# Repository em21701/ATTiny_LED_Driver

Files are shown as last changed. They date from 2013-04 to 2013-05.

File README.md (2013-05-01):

ATTiny_LED_Driver
=================

LED Driver Board using and ATTiny processor for PWM and effects.

The goal of this project is to use the ATTiny as a Buck Driver for High Brightness LEDs. 
After getting a functional Buck Driver working I will add blink effects.

This driver board has 2 inputs and is intended for use as a turn signal/running light 
combo and brake light/running light combo for a motorcycle. As such the board has 2 inputs,
one for 12v power from the key and a second for 12v power from either the turn signal or 
brake light. The Key inuput will illuminate the LEDs to a low level and the second input 
will change the brightness to a significantly higher level.Blink effects will be added when 
used as a tail/brake combo to make the light more conspicuous. 

Currently planned blink effects are an invverted heartbeat and flash and fade. In the heart 
beat pattern the light will dim in a lub-dub pattern while brake light is illuminated. 
In the flash and fade pattern, the brake light will flash to full brightness then slowly fade
to a level brighter than running light level, but noticeably lower than full brightness. The
light will then flash back to full brightness and repeat.

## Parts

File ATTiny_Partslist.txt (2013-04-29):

Partlist

Exported from ATTiny5.sch at 4/17/13 7:26 PM

EAGLE Version 6.4.0 Copyright (c) 1988-2013 CadSoft

Assembly variant: 

Part     Value           Device          Package          Library                    Sheet

C1       .1u             C-USC0805       C0805            resistor                   1
C2       .1u             C-USC0805       C0805            resistor                   1
D1       CD1206-B260     CD1206-B260     D1206            Personal                   1
L1       B82442H1104K    B82442H1104K    B82442H          Personal                   1
Q1       BSP100          BSP100          SOT223           Personal                   1
R1       10k             R-US_R1206      R1206            resistor                   1
R2       .1              R-US_R1206      R1206            resistor                   1
R3       10k             R-US_R1206      R1206            resistor                   1
R4       900             R-US_R1206      R1206            resistor                   1
R5       300             R-US_R1206      R1206            resistor                   1
U1       SPX5205M5-L-3-3 SPX5205M5-L-3-3 SOT95P280X145-5N Exar_By_element14_Batch_1  1
U2       ATTINY5-TSHR    ATTINY5-TSHR    SOT95P280X145-6N Atmel_By_element14_Batch_1 1
X1       DIODES          MPT2            2POL254          con-phoenix-254            1
X2                       MPT3            3POL254          con-phoenix-254            1

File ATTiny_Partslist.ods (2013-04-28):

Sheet: Parts List
Part | Value | Package | Qty | $ | Sub $ | Digikey
C1,C2 | .1u | C0805 | 2 | 0.1 | 0.2 | 445-7534-1-ND
D1 | CD1206-B260 | D1206 | 1 | 0.47 | 0.47 | CD1206-B260CT-ND
L1 | 100u |  | 1 | 0.54 | 0.54 | SRN8040-101MCT-ND
Q1 | BSP100 | SOT223 | 1 | 0.69 | 0.69 | 568-6956-1-ND
R1,R3 | 10k | R1206 | 2 | 0.094 | 0.188 | 541-10KECT-ND
R2 | 1 | R1206 | 1 | 0.1 | 0.1 | CRM1206-JW-1R0ELFCT-ND
R4 | 900 | R1206 | 1 | 0.1 | 0.1 | P910ECT-ND
R5 | 300 | R1206 | 1 | 0.1 | 0.1 | P300ECT-ND
U1 | SPX5205M5-L-3-3 | SOT95P280X145-5N | 1 | 0.66 | 0.66 | 1016-1878-1-ND
U2 | ATTINY5-TSHR | SOT95P280X145-6N | 1 | 0.67 | 0.67 | ATTINY5-TSHRCT-ND
 |  |  |  | Total | 3.718

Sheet: Pinouts
Mounting Holes
x | y | size
0.060 | 0.530 | 0.125
1.120 | 0.060 | 0.125
Programming pins
x | y | Connection
0.200 | 0.375 | GND
0.390 | 0.280 | TPICLK
0.350 | 0.210 | V+
0.570 | 0.400 | TPIDATA
0.590 | 0.275 | RESET

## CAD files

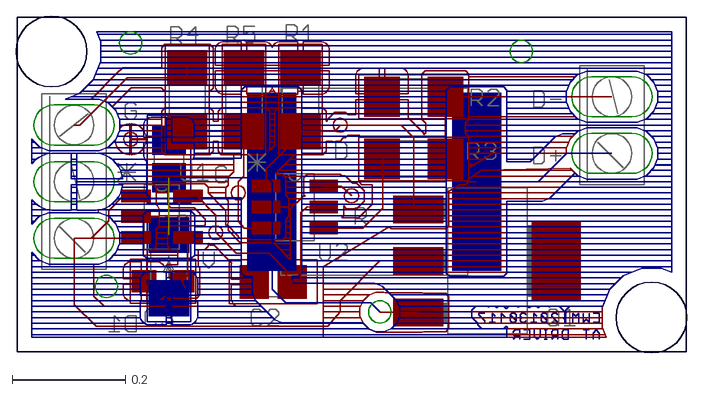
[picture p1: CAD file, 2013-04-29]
ATTiny5.dxf
1.19 x 0.595

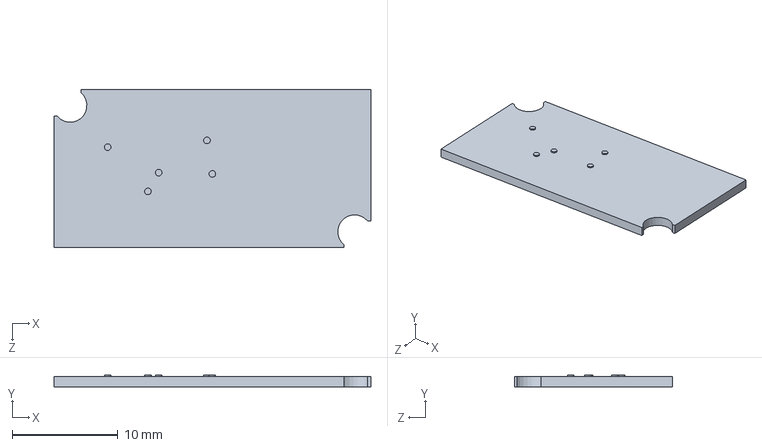
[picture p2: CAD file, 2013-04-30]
Programmer/Board.SLDPRT
30.0 x 1.13 x 15.0 mm

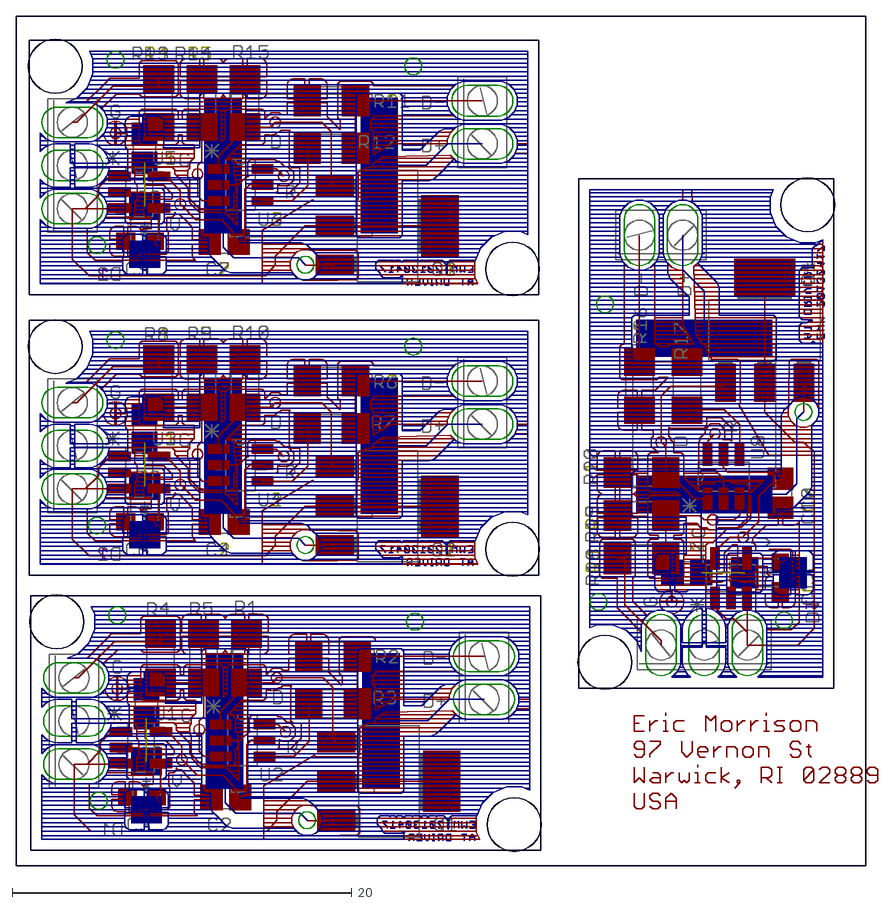
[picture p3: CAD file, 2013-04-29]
Panel/ATTinyPanel.dxf
50.7 x 50.0

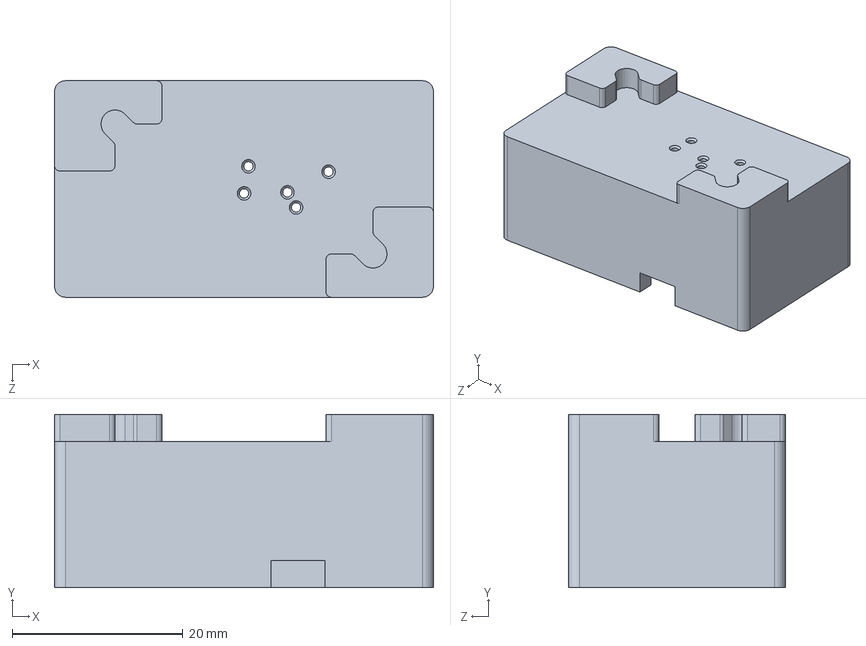
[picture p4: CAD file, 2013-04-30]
Programmer/Fixture_Base.SLDPRT
44.5 x 20.3 x 25.4 mm

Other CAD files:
Panel/ATTinyPanelBoardOutlinesOnly.dxf
Programmer/Fixture_Base.DXF
Programmer/Fixture_Base.SLDDRW

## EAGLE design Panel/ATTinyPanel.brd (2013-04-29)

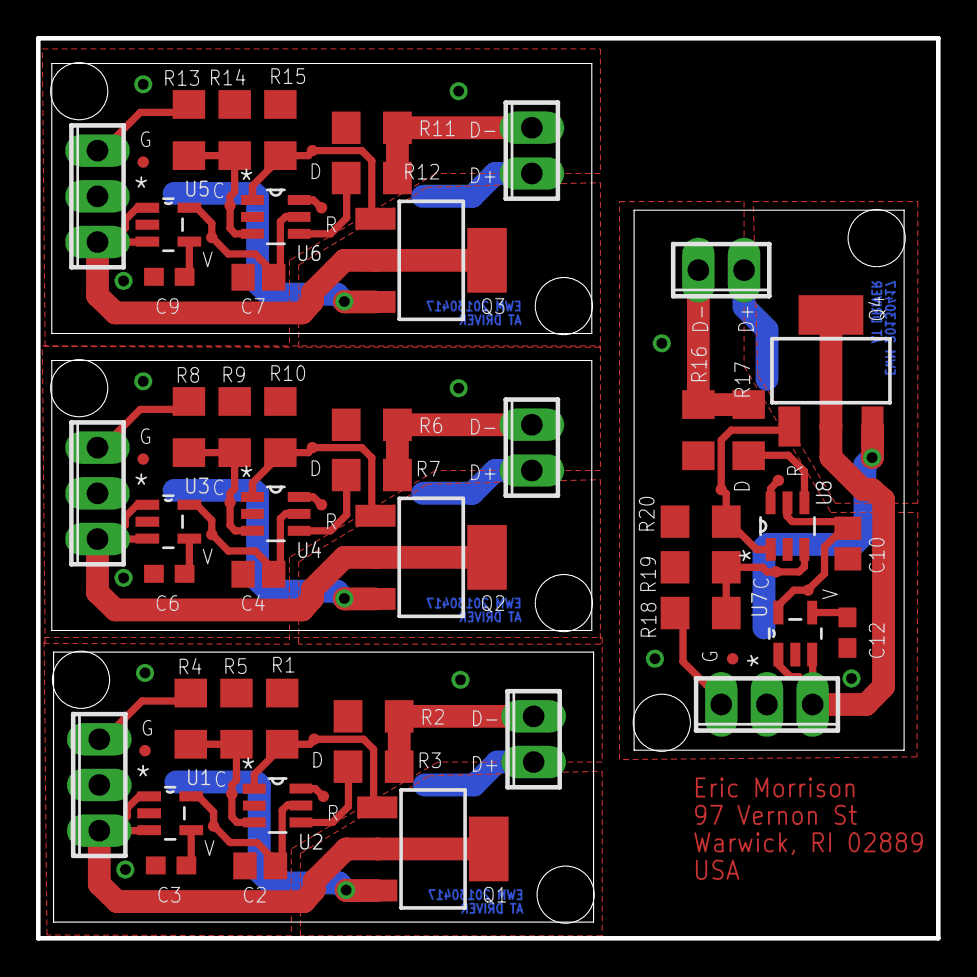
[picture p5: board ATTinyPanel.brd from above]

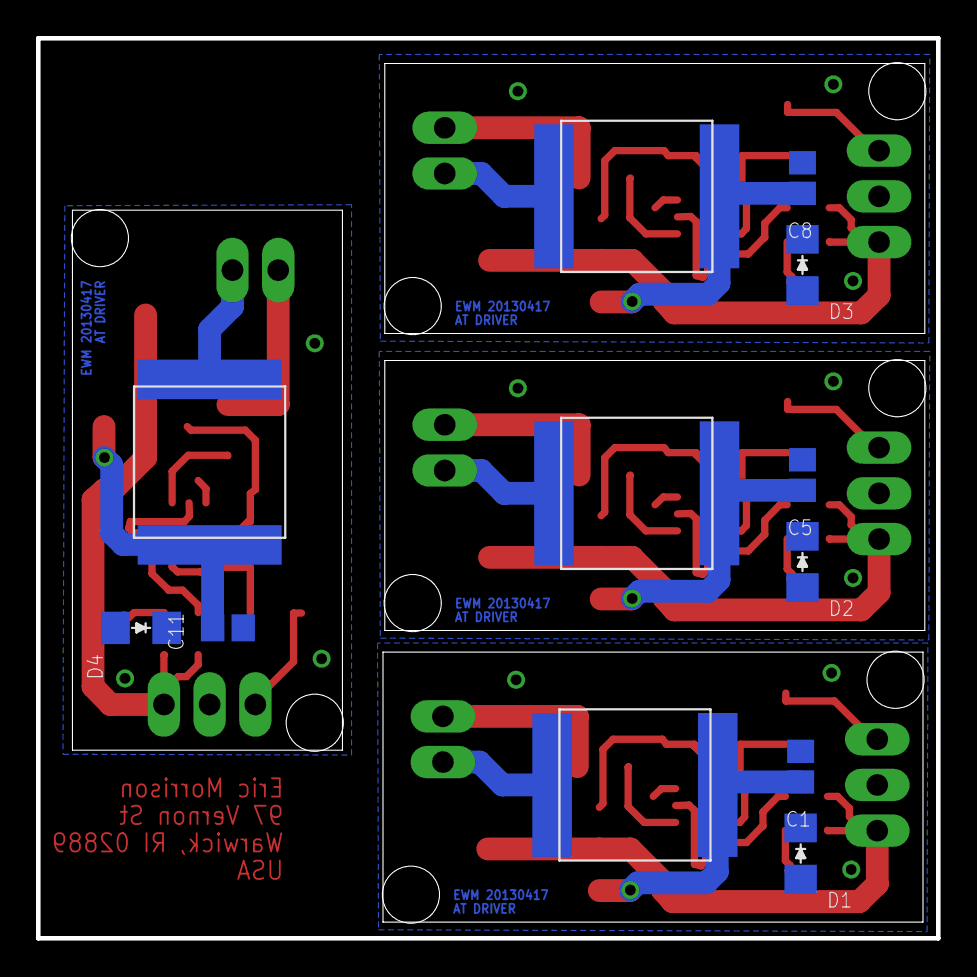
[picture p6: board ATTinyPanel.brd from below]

Board: 2 copper layers, 50.0 x 50.0 mm, 80 parts (12 on the bottom side), 48 nets.

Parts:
+5V, +5V1, +5V2, +5V3: TPI; TPI_PAD
C1, C2, C4, C5, C7, C8, C10, C11: .1u; C0805
C3, C6, C9, C12: 10n; C0603
D1, D2, D3, D4: CD1206-B260; D1206
GND, GND1, GND2, GND3: TPI; TPI_PAD
L1, L2, L3, L4: SRN8040
Q1, Q2, Q3, Q4: BSP100; SOT223
R1, R3, R7, R10, R12, R15, R17, R20: 10k; R1206
R2, R6, R11, R16: 1; R1206
R4, R8, R13, R18: 900; R1206
R5, R9, R14, R19: 300; R1206
RESET, RESET1, RESET2, RESET3: TPI; TPI_PAD
TPICLK, TPICLK1, TPICLK2, TPICLK3: TPI; TPI_PAD
TPIDATA, TPIDATA1, TPIDATA2, TPIDATA3: TPI; TPI_PAD
U1, U3, U5, U7: SPX5205M5-L-3-3; SOT95P280X145-5N
U2, U4, U6, U8: ATTINY5-TSHR; SOT95P280X145-6N
X1, X4, X6, X8: DIODES; 2POL254
X2, X3, X5, X7: INPUT; 3POL254

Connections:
+14V: Q1.2, Q1.TAB, U1.1, U1.3, X2.1
+14V1: Q2.2, Q2.TAB, U3.1, U3.3, X3.1
+14V2: Q3.2, Q3.TAB, U5.1, U5.3, X5.1
+14V3: Q4.2, Q4.TAB, U7.1, U7.3, X7.1
BLINK: R4.1, R5.1, TPICLK.P$1, U2.3
BLINK1: R8.1, R9.1, TPICLK1.P$1, U4.3
BLINK2: R13.1, R14.1, TPICLK2.P$1, U6.3
BLINK3: R18.1, R19.1, TPICLK3.P$1, U8.3
D-: R2.2, R3.1, X1.2
D-1: R6.2, R7.1, X4.2
D-2: R11.2, R12.1, X6.2
D-3: R16.2, R17.1, X8.2
GND: C1.2, C2.2, C3.2, D1.2, GND.P$1, R1.1, R2.1, R5.2, U1.2, U2.2, X2.2
GND1: C4.2, C5.2, C6.2, D2.2, GND1.P$1, R6.1, R9.2, R10.1, U3.2, U4.2, X3.2
GND2: C7.2, C8.2, C9.2, D3.2, GND2.P$1, R11.1, R14.2, R15.1, U5.2, U6.2, X5.2
GND3: C10.2, C11.2, C12.2, D4.2, GND3.P$1, R16.1, R19.2, R20.1, U7.2, U8.2, X7.2
L+: C1.1, D1.1, L1.P$1, Q1.3
L+1: C5.1, D2.1, L2.P$1, Q2.3
L+2: C8.1, D3.1, L3.P$1, Q3.3
L+3: C11.1, D4.1, L4.P$1, Q4.3
MEASURE: R3.2, U2.4
MEASURE1: R7.2, U4.4
MEASURE2: R12.2, U6.4
MEASURE3: R17.2, U8.4
MOSFET: Q1.1, R1.2, TPIDATA.P$1, U2.1
MOSFET1: Q2.1, R10.2, TPIDATA1.P$1, U4.1
MOSFET2: Q3.1, R15.2, TPIDATA2.P$1, U6.1
MOSFET3: Q4.1, R20.2, TPIDATA3.P$1, U8.1
unnamed: R4.2, X2.3
unnamed: C3.1, U1.4
unnamed: L1.P$2, X1.1
unnamed: L2.P$2, X4.1
unnamed: R8.2, X3.3
unnamed: C6.1, U3.4
unnamed: L3.P$2, X6.1
unnamed: R13.2, X5.3
unnamed: C9.1, U5.4
unnamed: L4.P$2, X8.1
unnamed: R18.2, X7.3
unnamed: C12.1, U7.4
RESET: RESET.P$1, U2.6
RESET1: RESET1.P$1, U4.6
RESET2: RESET2.P$1, U6.6
RESET3: RESET3.P$1, U8.6
VCC: +5V.P$1, C2.1, U1.5, U2.5
VCC1: +5V1.P$1, C4.1, U3.5, U4.5
VCC2: +5V2.P$1, C7.1, U5.5, U6.5
VCC3: +5V3.P$1, C10.1, U7.5, U8.5

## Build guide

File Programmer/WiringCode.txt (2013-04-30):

PIN	Wire
G	Black
V	White
C	Gray
D	Purple
R	Blue

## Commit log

2013-04-28 inital git version
    [ATTiny5.brd, ATTiny5.sch, ATTiny_Partslist.ods]
2013-04-29 Added Code and Panel dirs. Updated Flowchart
    [ATTiny5.dxf, ATTiny5.sch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]
2013-04-29 Flow Chart change
    Flow chart changed from: PWM = Gain*Error to: PWM += Gain*Error
2013-04-30 Added programming hardware directory
    Includes solidworks files for the board, programming fixture, and a txt
    file with wiring color code.
    [Board.SLDPRT, Fixture_Base.DXF, Fixture_Base.SLDDRW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]
